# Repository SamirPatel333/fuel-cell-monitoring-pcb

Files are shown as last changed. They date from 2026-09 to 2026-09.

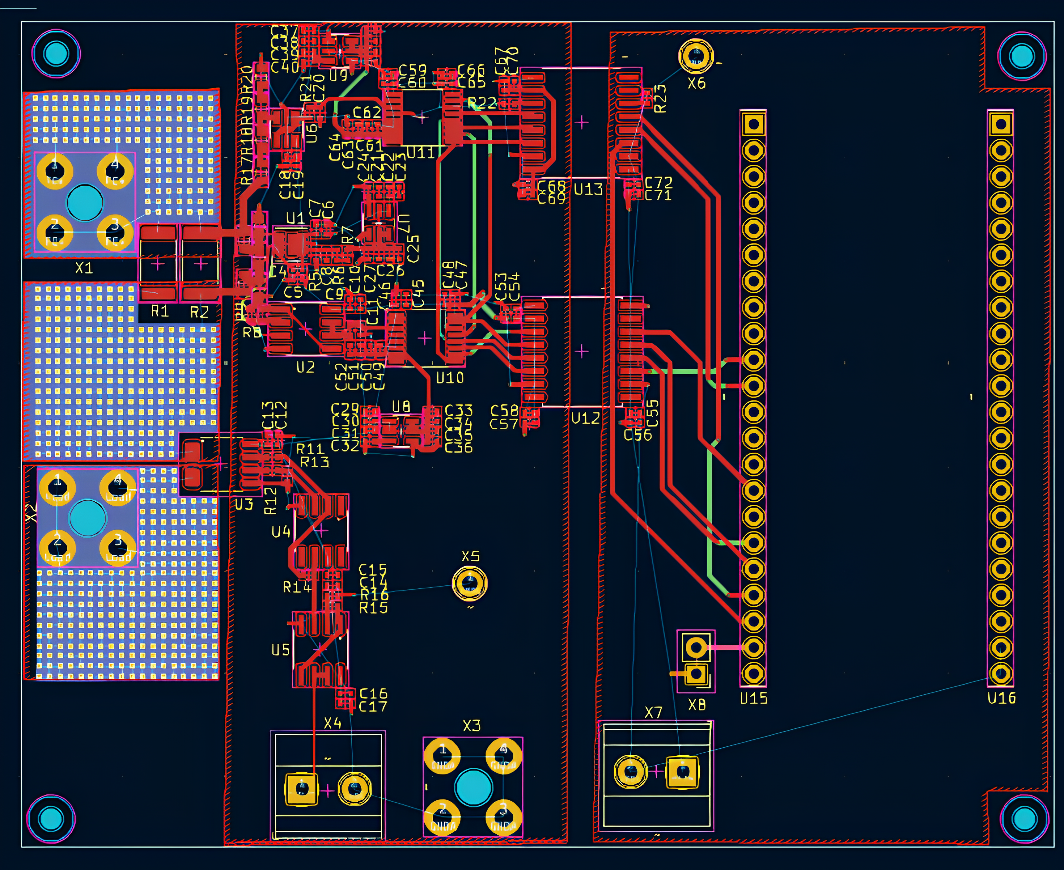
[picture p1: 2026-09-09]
Docs/Images/PCB_layout.png

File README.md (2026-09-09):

# Fuel Cell Monitoring System – 6-Layer PCB

## Overview

A custom **6-layer mixed-signal PCB** designed in **KiCad** for monitoring a **PEM fuel cell system**.

The board measures fuel-cell voltage and current, conditions the analog signals, performs ADC conversion, provides digital isolation, and interfaces with an **ESP32-S3**.

## Main Features

- Fuel-cell voltage measurement
- Fuel-cell current measurement up to 20 A
- Analog signal conditioning and filtering
- Precision voltage references
- High-resolution ADC measurement
- Digital isolation
- ESP32-S3 interface

## Main Components

| Component | Function |
|---|---|
| ESP32-S3 | Microcontroller |
| ADS8329 | ADC |
| MAX49925 | Current measurement |
| MAX6070 | Precision voltage reference |
| AD8031 / AD8032 | Analog signal conditioning |
| ADA4099 | Precision analog amplifier |

## PCB Design

The PCB is designed as a **6-layer mixed-signal board** using KiCad.

The multilayer design supports:

- Analog and digital signal separation
- Stable power and ground distribution
- Sensitive ADC signal routing
- High-current routing
- Improved signal integrity and noise performance

## Design Tools

- KiCad – Schematic capture and PCB layout
- ESP32-S3 – Microcontroller interface
- Multilayer PCB design for mixed-signal applications

## Project Structure

- `Kicad/` – KiCad schematics, PCB layout, symbols and footprints
- `Docs/` – Project report and documentation images
- `.gitignore` – Files excluded from Git tracking

## Project Status

PCB schematic and 6-layer PCB layout completed in KiCad.

## Future Improvements

- PCB manufacturing and assembly
- Hardware testing and calibration
- ESP32-S3 firmware development
- Measurement accuracy and noise evaluation

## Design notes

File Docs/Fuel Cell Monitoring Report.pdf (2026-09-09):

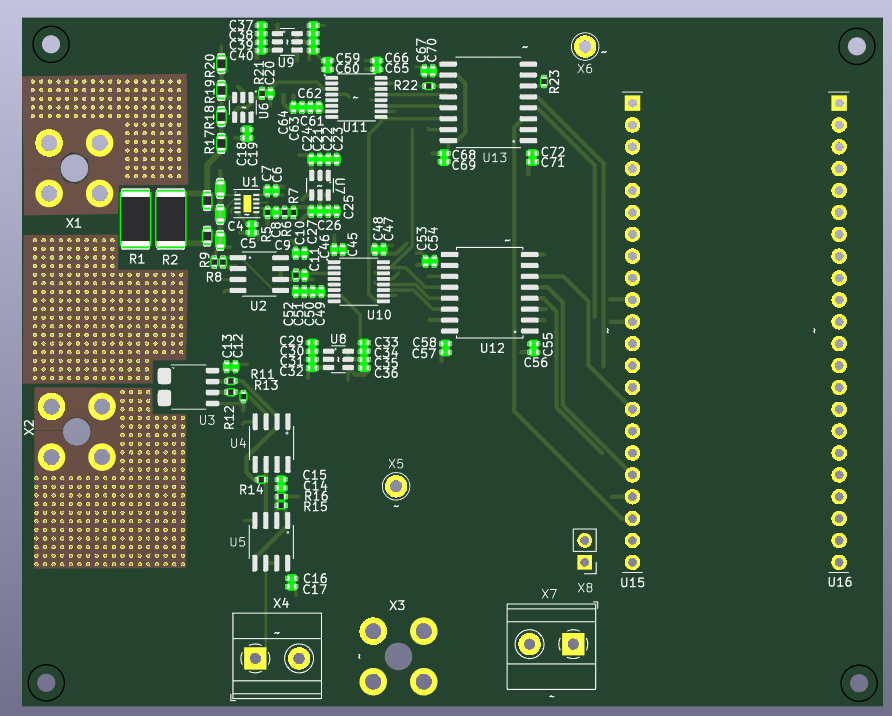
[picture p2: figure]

Fuel Cell Monitoring System | Six-Layer PCB Design | Page 1

# FUEL CELL MONITORING SYSTEM

### Six-Layer PCB Design & Hardware Engineering Report

Figure 1. 3D visualization of the completed six-layer PCB layout.

Project | Fuel Cell Monitoring System
PCB Technology | 6-layer printed circuit board
EDA Tool | KiCad
Controller | ESP32-S3
Measurement Functions | Fuel-cell voltage and current monitoring
Author | Samir Patel
Institution | Hochschule Wismar – Faculty of Engineering Sciences

## Engineering Report

This report documents the schematic architecture, measurement signal conditioning, ADC and isolation interfaces, reference-voltage generation, microcontroller interface, and six-layer PCB implementation developed for a fuel-cell monitoring application.

# Contents

### 1 Project Overview

### 2 System Architecture

### 3 Voltage Measurement Chain

### 4 Current Measurement Chain

### 5 Voltage References and Power Integrity

### 6 ADC, Digital Isolation and SPI Interface

### 7 Microcontroller Interface

### 8 Six-Layer PCB Design and Layout

### 9 Design-for-Manufacture and Verification

### 10 Engineering Assessment

### 11 Conclusion and Future Improvements

## List of Figures

- Figure 1. 3D visualization of the six-layer PCB.
- Figure 2. KiCad PCB layout and routing view.
- Figure 3. Main current/voltage measurement circuitry.
- Figure 4. Voltage measurement and conditioning stage.
- Figure 5. Precision reference-voltage circuits.
- Figure 6. ADC and digital-isolation interface – channel 1.
- Figure 7. ADC and digital-isolation interface – channel 2.
- Figure 8. ESP32-S3 microcontroller interface.

# 1. Project Overview

The project is a dedicated electronic monitoring board for a fuel-cell system. The hardware is designed to acquire electrical operating quantities, condition them for accurate analog-to-digital conversion, provide isolation where required, and transfer the resulting measurement data to an ESP32-S3 microcontroller through digital interfaces.

## Main engineering objectives

- Measure the fuel-cell output voltage using a conditioned analog measurement path.
- Measure fuel-cell current using a dedicated current-sensing stage.
- Scale, buffer and filter analog signals before ADC conversion.
- Provide stable analog reference voltages for repeatable measurement.
- Use digital isolation between measurement-side circuitry and the controller-side interface.
- Implement the complete design as a compact six-layer PCB in KiCad.
- Provide a layout suitable for further prototype fabrication, assembly and laboratory validation.

## Design philosophy

The design separates the analog measurement functions from the digital controller section. This is important because low-level measurement signals are sensitive to supply noise, return-current paths and digital switching activity. The use of dedicated filtering, buffering, reference circuitry and isolation supports a more controlled measurement environment.

# 2. System Architecture

The schematic is organized into functional blocks rather than treating the PCB as a single circuit. The principal signal flow is: fuel-cell input → sensing → analog conditioning → ADC → digital isolation → ESP32-S3 controller. Separate reference and supply-conditioning circuits support the measurement stages.

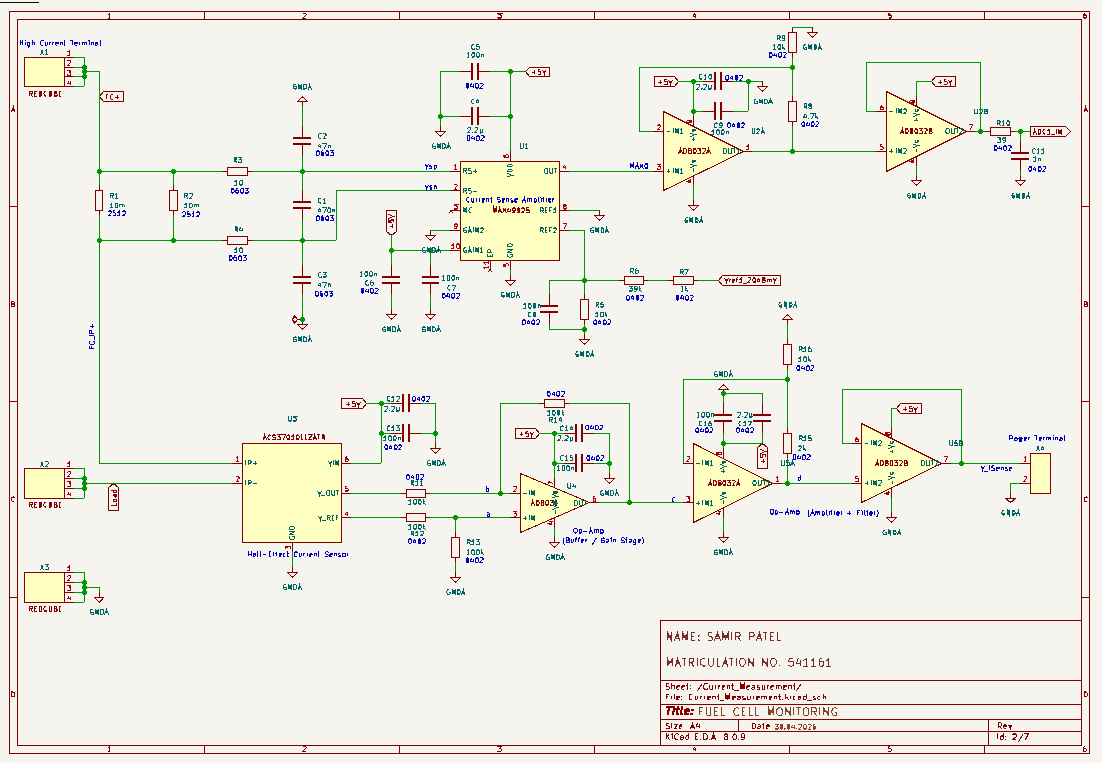
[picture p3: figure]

Figure 3. Main measurement circuitry showing voltage/current sensing, analog conditioning and output stages.

## Functional blocks visible in the design

- Fuel-cell electrical input and high-current connection interfaces.
- Voltage sensing network with resistor-divider scaling and filtering.
- Current measurement using a dedicated current-sensing device and amplifier chain.
- Operational-amplifier stages for buffering, gain and signal conditioning.
- Precision voltage-reference sections with local decoupling.
- High-resolution ADC interfaces for digitizing conditioned measurement signals.
- Digital isolators for separation of the measurement and controller domains.
- ESP32-S3 interface and SPI/control connections.

# 3. Voltage Measurement Chain

The voltage-monitoring section converts the fuel-cell voltage into a controlled low-voltage analog signal suitable for the ADC input range. The front end uses resistor scaling, followed by filtering and an amplifier/buffer stage. This approach prevents the high-voltage source from being connected directly to the ADC while maintaining a defined measurement relationship.

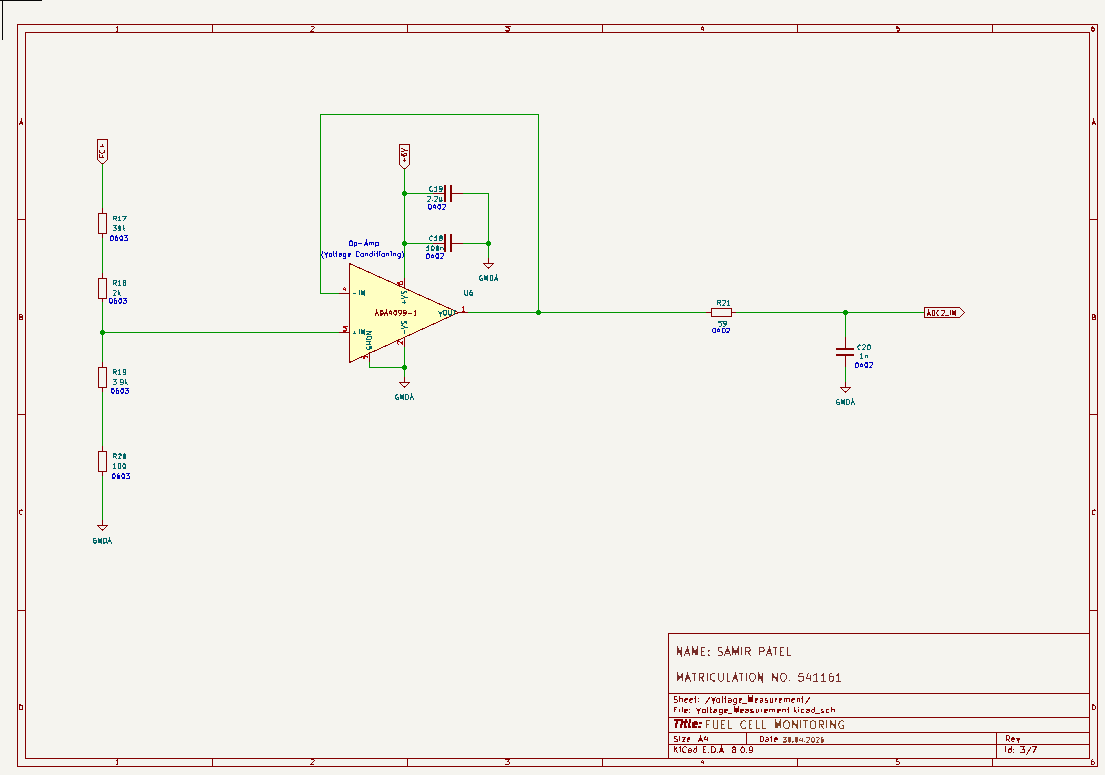
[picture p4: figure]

Figure 4. Voltage measurement and conditioning stage in KiCad.

## Key design considerations

- The resistor divider establishes the input scaling ratio.
- RC filtering reduces high-frequency noise before conversion.
- The op-amp stage provides buffering and/or additional signal conditioning.
- The final signal is routed to the ADC through a controlled analog path.
- Local supply decoupling is used around active devices.

## Measurement relationship

For a basic divider, the scaled voltage is determined by the resistor ratio. During laboratory calibration, the actual board should be characterized using a known reference voltage and the measured ADC code should be mapped to the physical fuel-cell voltage. Component tolerances, amplifier offset and ADC reference accuracy should be included in the final error budget.

# 4. Current Measurement Chain

The current-monitoring path uses a dedicated current-sensing element followed by analog signal conditioning. The schematic includes amplifier stages that prepare the sensor output for ADC conversion. The design therefore allows the low-level current-sense signal to be amplified and filtered before digitization.

## Signal-conditioning strategy

- Current sensor generates a signal proportional to the measured current.
- An amplifier stage increases the useful signal level.
- RC networks provide bandwidth limitation and noise suppression.
- The conditioned signal is transferred to the ADC input.
- The final current value can be calculated in firmware from ADC code and the calibrated sensor transfer function.

The current channel should be calibrated at several known operating points rather than using only one point. A two-point or multi-point calibration can compensate for gain and offset errors and provide better accuracy over the operating range.

# 5. Voltage References and Power Integrity

Stable reference voltages are essential for accurate ADC measurements. The design contains dedicated reference-voltage circuits with multiple bypass capacitors placed around the reference devices. The repeated reference blocks indicate an intentional effort to provide clean reference rails for the measurement channels.

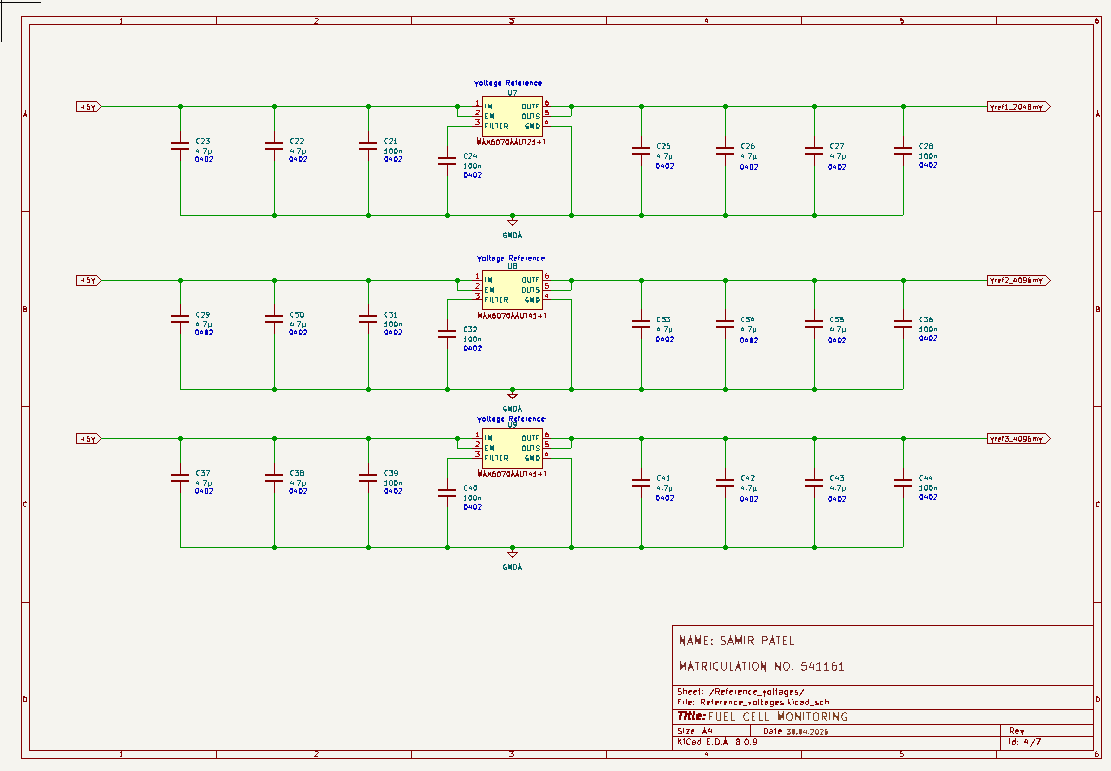
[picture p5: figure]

Figure 5. Dedicated voltage-reference circuits with local bypass capacitors.

## Power-integrity practices

- Place high-frequency bypass capacitors close to IC supply/reference pins.
- Keep sensitive reference routing away from noisy digital traces where practical.
- Use a controlled return path for analog circuitry.
- Avoid unnecessary shared impedance between high-current and low-level measurement returns.
- Verify reference output voltage and noise experimentally during board bring-up.

# 6. ADC, Digital Isolation and SPI Interface

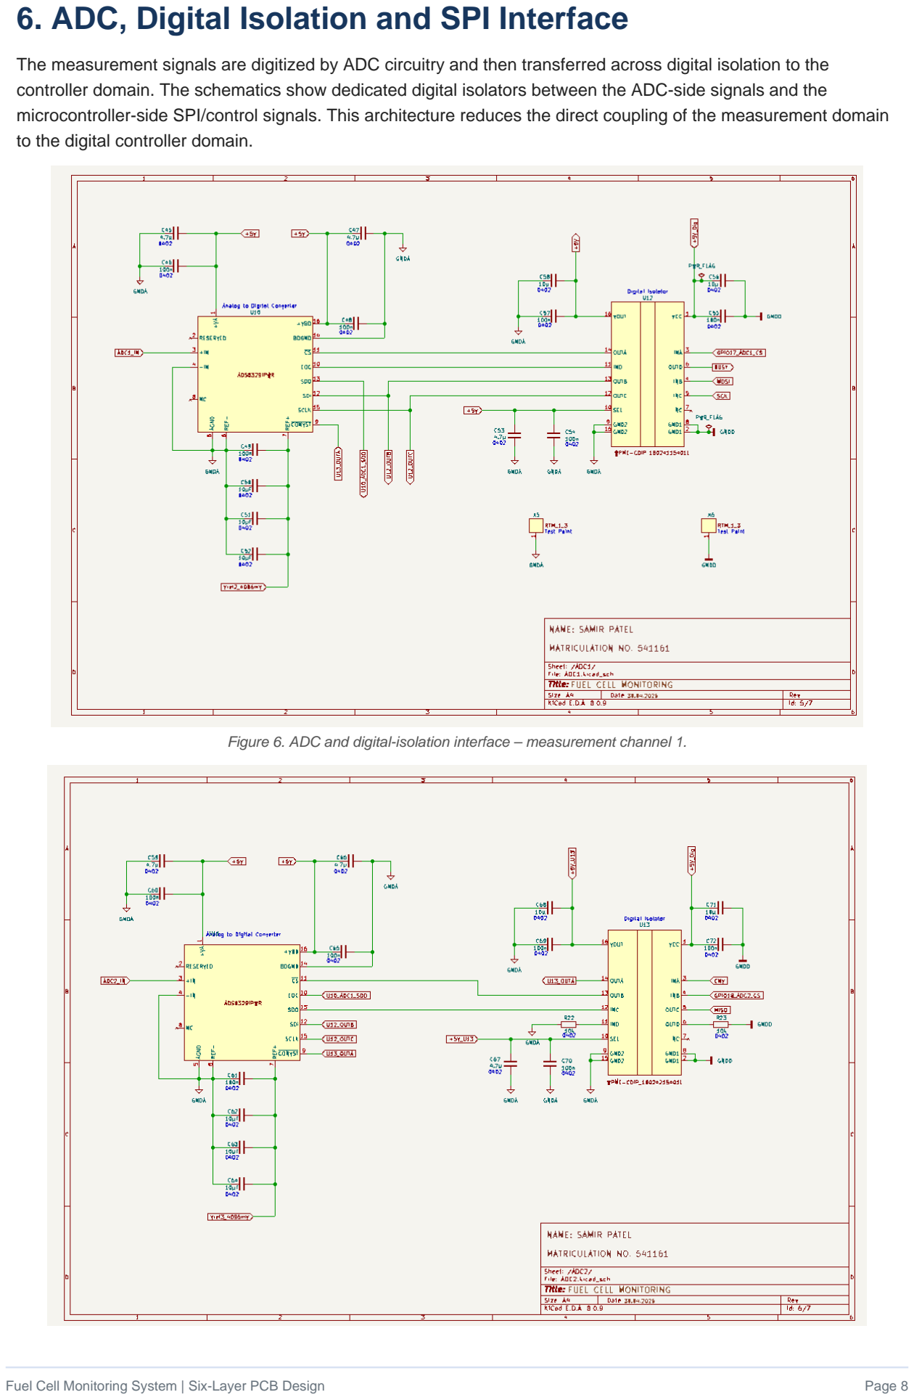
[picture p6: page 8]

The measurement signals are digitized by ADC circuitry and then transferred across digital isolation to the controller domain. The schematics show dedicated digital isolators between the ADC-side signals and the microcontroller-side SPI/control signals. This architecture reduces the direct coupling of the measurement domain to the digital controller domain.

Figure 6. ADC and digital-isolation interface – measurement channel 1.

Figure 7. ADC and digital-isolation interface – measurement channel 2.

## Interface signals

- SPI clock and data signals connect the ADC and controller interface.
- Chip-select and control lines are routed through the digital interface.
- Isolated power domains are supported by local decoupling.
- The PCB layout keeps the digital interface physically separated from the most sensitive analog nodes where practical.

# 7. Microcontroller Interface

The controller section is centered around an ESP32-S3 module. The schematic provides the required power, ground and digital signal connections for communication with the measurement subsystem. The large board-side header area provides flexibility for programming, debugging and system integration.

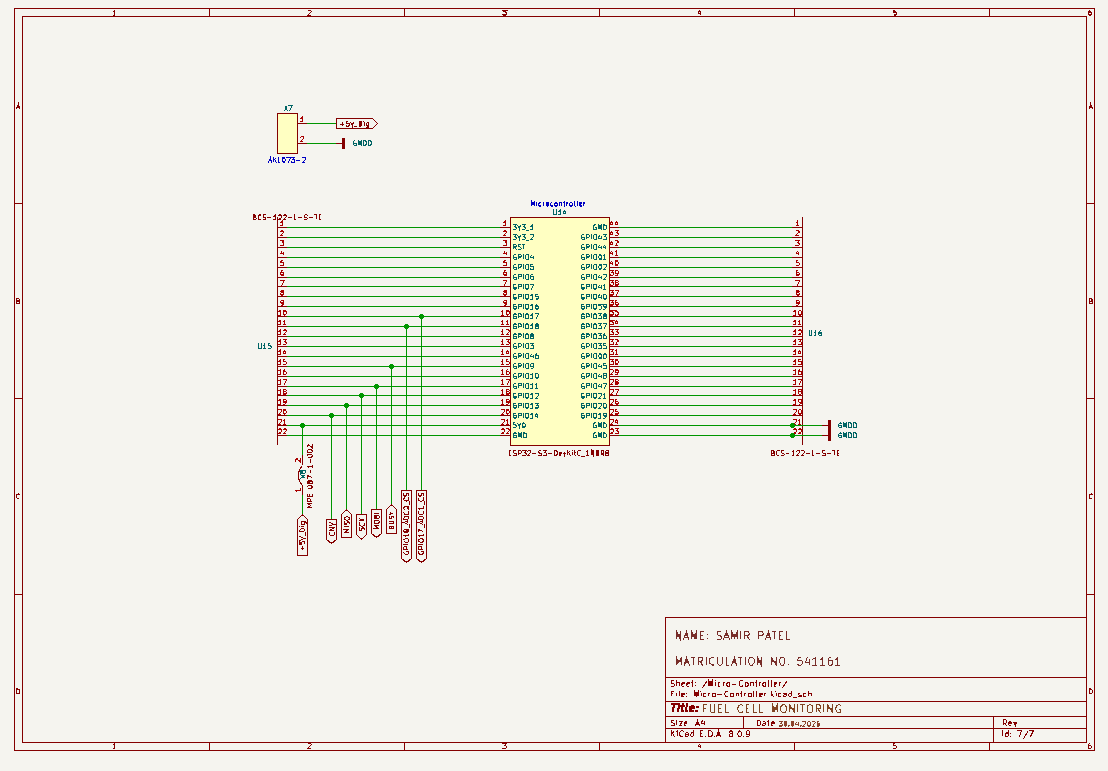
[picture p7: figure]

Figure 8. ESP32-S3 microcontroller and external interface connections.

## Recommended firmware responsibilities

- Initialize the ADC/SPI interface and digital-isolation control signals.
- Read raw ADC conversion results.
- Apply gain, offset and calibration coefficients.
- Convert ADC results into engineering units such as volts and amperes.
- Provide diagnostic checks for out-of-range or invalid measurements.
- Transmit measurements through the selected communication interface.

# 8. Six-Layer PCB Design and Layout

The board was implemented as a six-layer PCB. The higher layer count provides additional routing and plane resources compared with a basic two-layer design and is particularly useful for a mixed-signal board containing precision analog circuitry, ADCs, digital isolation and a microcontroller interface.

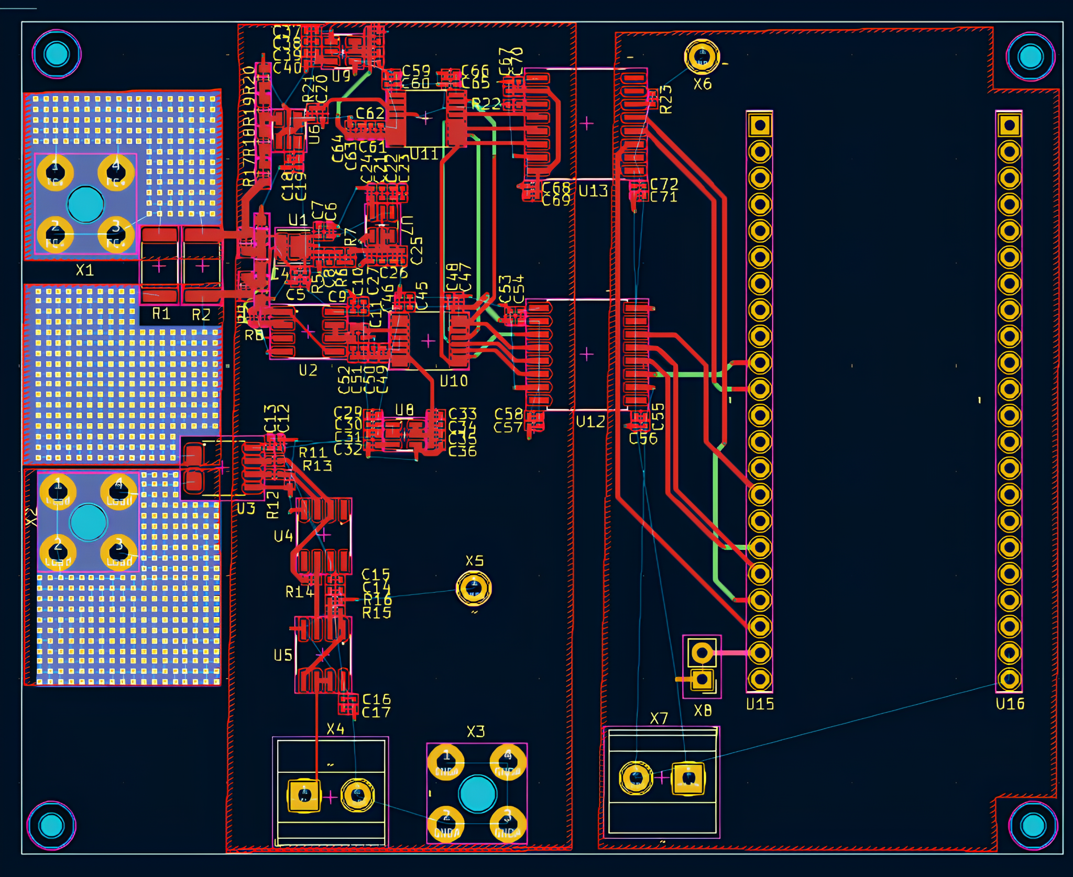
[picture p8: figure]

Figure 2. KiCad PCB layout view showing component placement and routed traces.

## Layout strategy

- High-current/input connector regions are kept toward the board edge.
- Analog sensing and conditioning circuitry is concentrated in the left/central area.
- ADC and isolation circuitry forms an interface between analog and digital sections.
- The controller/header area is separated from the most sensitive analog circuitry.
- Large connector/header footprints provide system-level access and expansion.
- Mounting holes and mechanical keep-out areas are incorporated into the board outline.

## Six-layer mixed-signal considerations

- Use dedicated or carefully controlled ground/reference planes.
- Keep fast digital routes away from sensitive analog inputs.
- Minimize loop area for ADC reference, amplifier feedback and decoupling paths.
- Route high-current paths with appropriate copper width and thermal considerations.
- Use short connections between IC supply pins and local bypass capacitors.
- Validate all clearances, drill sizes, annular rings and copper-to-edge rules against the selected PCB manufacturer.

# 9. Design-for-Manufacture and Verification

Before fabrication, the KiCad project should be treated as a manufacturing data package rather than only a layout. The following checks are recommended for the final revision.

Area | Verification item | Status
Schematic | ERC completed and all intentional warnings reviewed | Check before release
PCB | DRC completed with no unexplained violations | Check before release
Footprints | Pad geometry, pin-1 orientation and mechanical dimensions verified | Check before release
Layers | Six copper layers and stack-up confirmed with manufacturer | Confirmed by project
Power | Supply rails and polarity checked | Check before release
References | Reference outputs measured under load | Prototype test
ADC | Input range and reference voltage verified | Prototype test
Isolation | Isolation barrier and creepage/clearance verified | Prototype test
Calibration | Voltage/current calibration coefficients established | Prototype test
Fabrication | Gerbers, drill files and assembly documentation generated | Release step

## Recommended release package

- KiCad project files: schematic, PCB layout, symbols and footprints.
- Fabrication outputs: Gerber and drill files for the six-layer stack-up.
- Bill of materials (BOM) with manufacturer part numbers.
- Pick-and-place data if automated assembly is used.
- PDF schematic and PCB drawings for documentation.
- Calibration and test procedure for prototype validation.

# 10. Engineering Assessment

The design demonstrates a complete hardware-development workflow from electrical sensing and analog conditioning through data conversion, digital isolation and microcontroller interfacing. The use of a six-layer PCB is appropriate for the density and mixed-signal nature of the design and gives the layout additional resources for signal integrity and power/ground distribution.

## Strengths of the current design

- Clear separation of major analog, conversion, isolation and controller functions.
- Dedicated analog conditioning before ADC conversion.
- Dedicated voltage-reference circuitry with multiple local capacitors.
- Digital isolation between measurement and controller interfaces.
- Compact six-layer PCB implementation with integrated connectors and mounting features.
- KiCad-based design is suitable for reproducible revision and manufacturing documentation.

## Areas to improve in the next revision

- Perform a complete quantitative error budget for voltage and current channels.
- Document the exact six-layer stack-up, copper thickness and impedance requirements.
- Add clearly documented test points for each major analog signal and supply rail.
- Review analog/digital return-current paths with particular attention to ADC reference and isolation boundaries.
- Complete prototype measurements for noise, offset, gain error and temperature drift.
- Add revision-controlled manufacturing and assembly documentation.

# 11. Conclusion and Future Improvements

A complete six-layer PCB-based fuel-cell monitoring platform has been developed in KiCad. The board integrates fuel-cell voltage and current measurement, analog signal conditioning, precision reference circuitry, ADC conversion, digital isolation and ESP32-S3 interfacing on a single hardware platform.

The next stage should focus on prototype fabrication and laboratory characterization. In particular, the voltage and current channels should be calibrated against traceable instruments, while ADC noise, amplifier offset, reference stability and thermal behavior should be measured. These results can then be used to refine component values, PCB routing and firmware calibration.

## Future development opportunities

- Add automated self-test and sensor fault detection.
- Implement digital filtering and configurable sampling rates in firmware.
- Add non-volatile storage for calibration coefficients.
- Provide a dedicated communication interface for PC or cloud-based monitoring.
- Improve test-point accessibility for production and laboratory debugging.
- Document and validate the complete PCB stack-up and EMC/EMI performance.
Document status | Professional project documentation
PCB revision | Six-layer design
Design tool | KiCad
Primary controller | ESP32-S3
Next milestone | Prototype fabrication and electrical validation

### End of Report

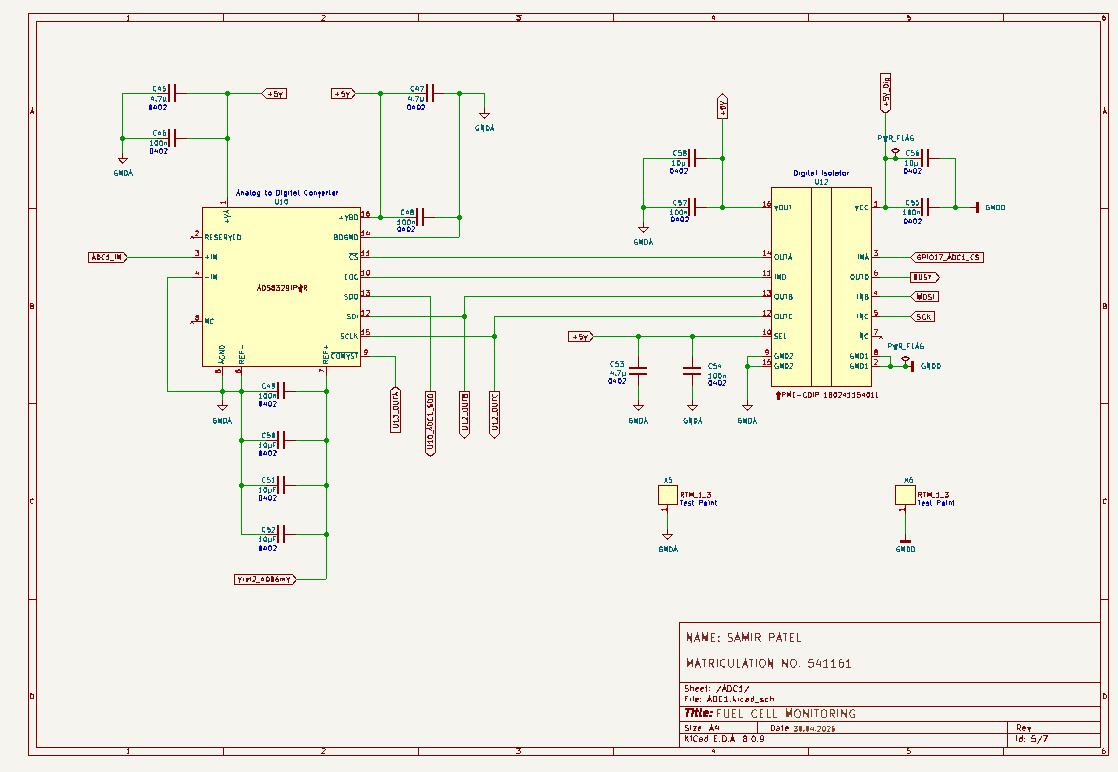
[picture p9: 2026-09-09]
Docs/Images/Schematic/ADC_1.png

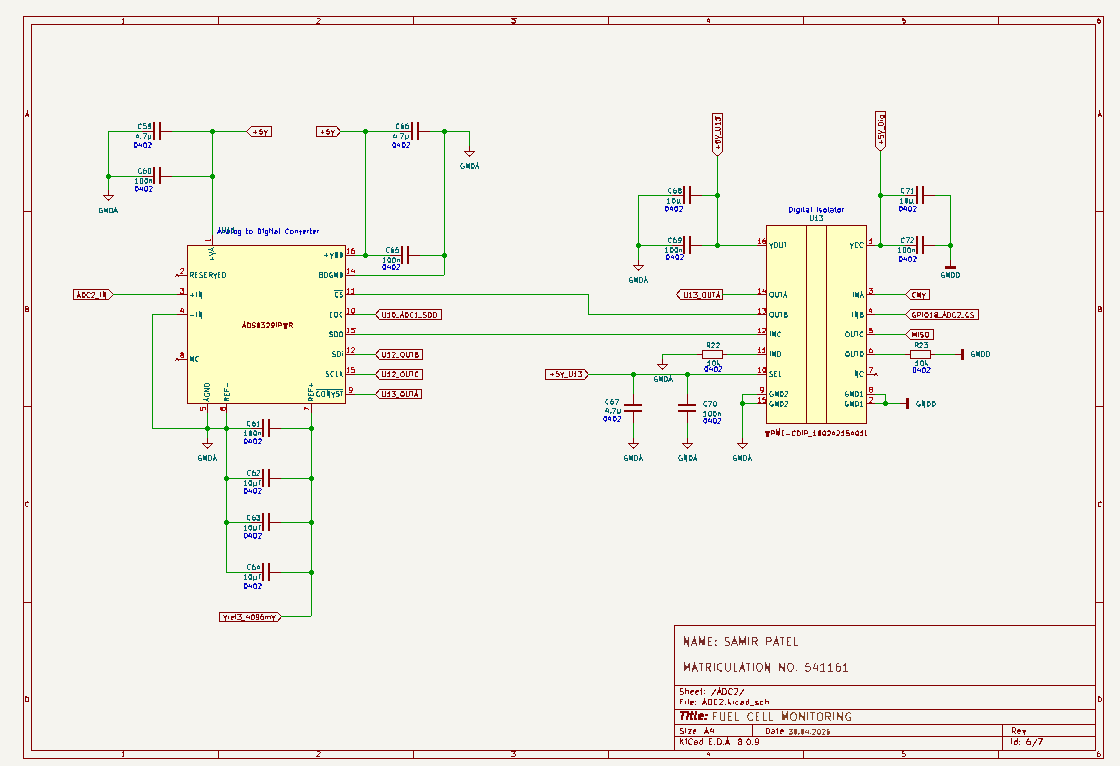
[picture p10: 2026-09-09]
Docs/Images/Schematic/ADC_2.png

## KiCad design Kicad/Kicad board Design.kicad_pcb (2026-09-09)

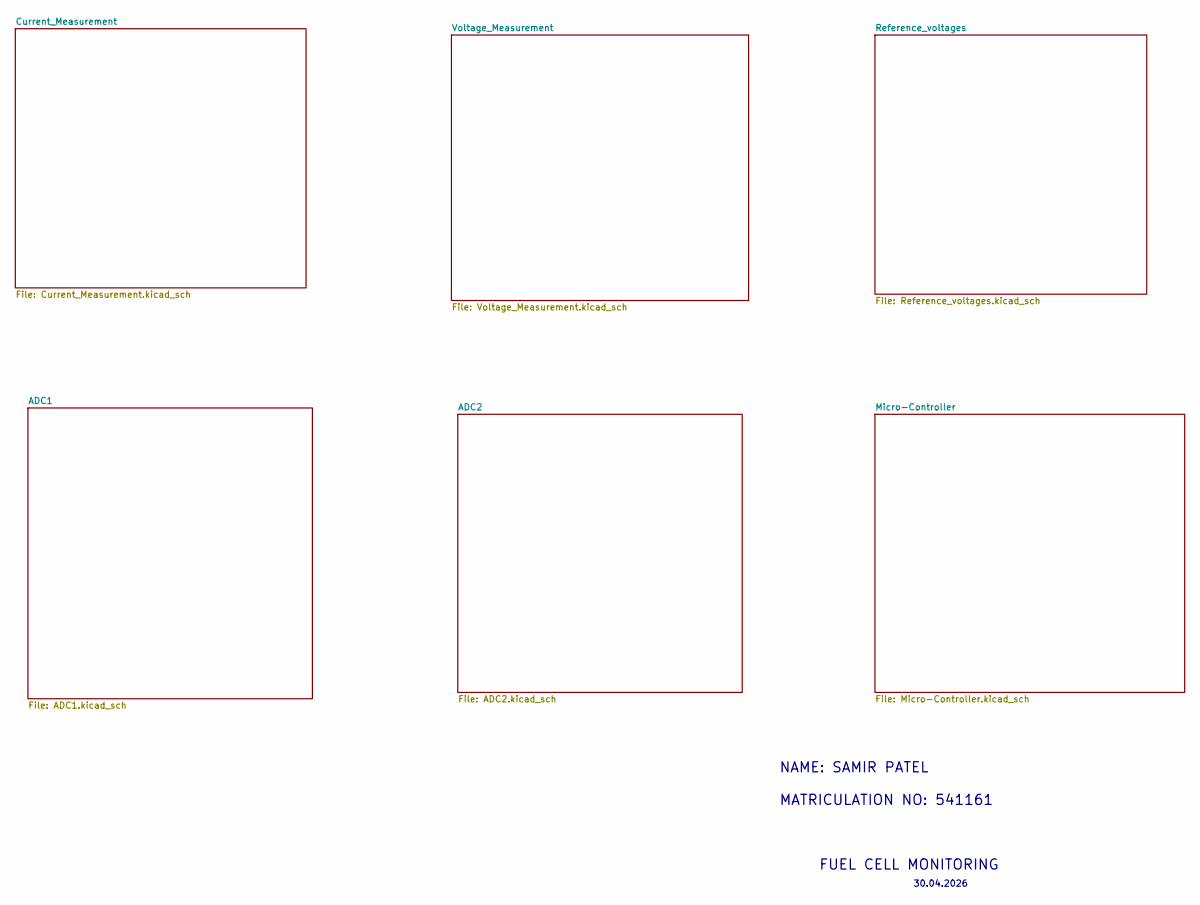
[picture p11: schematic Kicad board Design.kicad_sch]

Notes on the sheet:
FUEL CELL MONITORING
30.04.2026
NAME: SAMIR PATEL MATRICULATION NO: 541161

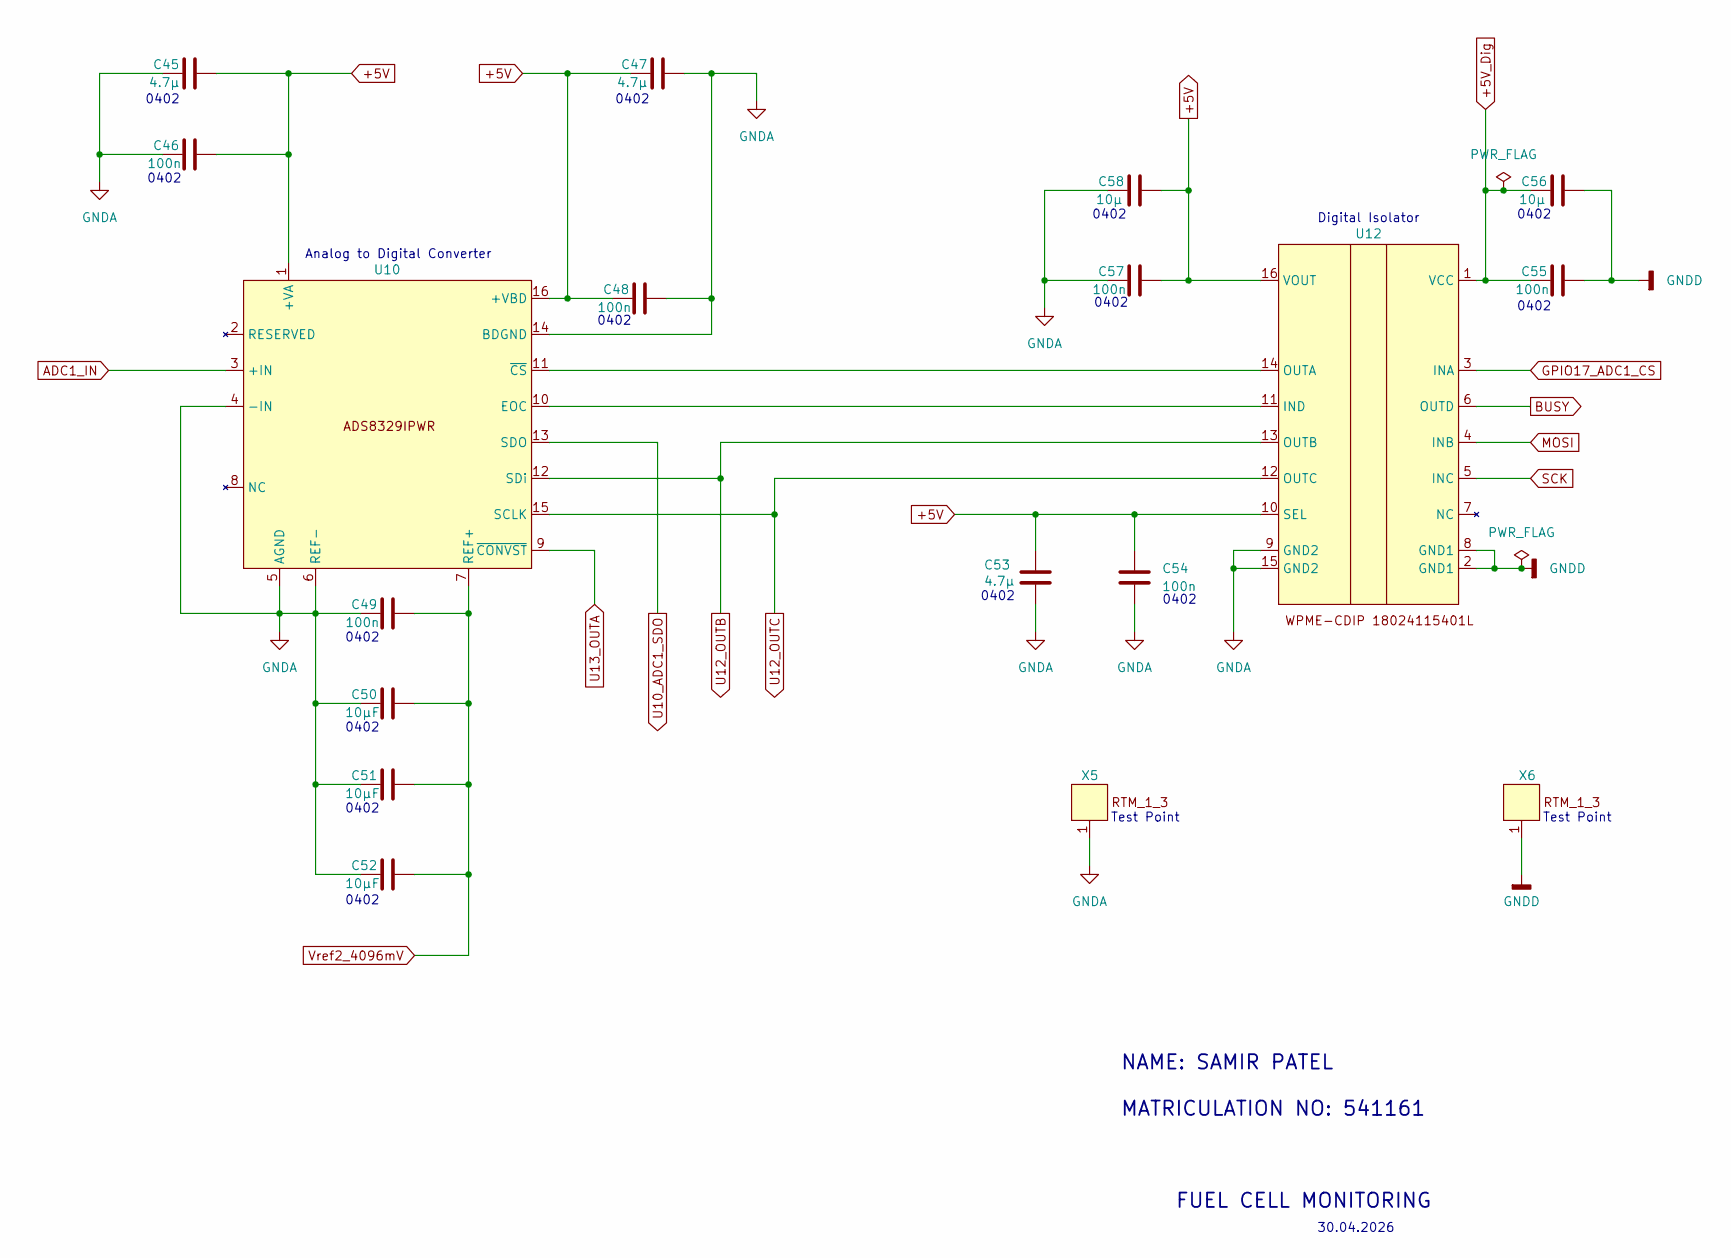
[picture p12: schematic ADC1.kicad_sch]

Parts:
C45, C47, C53: 4.7µ; C_0402_1005Metric
C46, C48, C49, C54, C55, C57: 100n; C_0402_1005Metric
C50, C51, C52: 10µF; C_0402_1005Metric
C56, C58: 10µ; C_0402_1005Metric
U10: ADS8329IPWR
U12: WPME-CDIP 18024115401L
X5, X6: RTM_1_3

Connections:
+5V: C45.2, C46.2, C47.1, C48.1, C53.1, C54.1, C57.2, C58.2, U10.1 (+VA), U10.16 (+VBD), U12.10 (SEL), U12.16 (VOUT); also elsewhere on the board
+5V_Dig: C55.1, C56.1, U12.1 (VCC); also elsewhere on the board
ADC1_IN: U10.3 (+IN); also elsewhere on the board
BUSY: U12.6 (OUTD); also elsewhere on the board
GNDA: C45.1, C46.1, C47.2, C48.2, C49.1, C50.1, C51.1, C52.1, C53.2, C54.2, C57.1, C58.1, U10.4 (-IN), U10.5 (AGND), U10.6 (REF-), U10.14 (BDGND), U12.9 (GND2), U12.15 (GND2), X5.1; also elsewhere on the board
GNDD: C55.2, C56.2, U12.2 (GND1), U12.8 (GND1), X6.1; also elsewhere on the board
GPIO17_ADC1_CS: U12.3 (INA); also elsewhere on the board
MOSI: U12.4 (INB); also elsewhere on the board
unnamed: U10.10 (EOC), U12.11 (IND)
unnamed: U10.11 (~CS), U12.14 (OUTA)
SCK: U12.5 (INC); also elsewhere on the board
U10_ADC1_SDO: U10.13 (SDO); also elsewhere on the board
U12_OUTB: U10.12 (SDi), U12.13 (OUTB); also elsewhere on the board
U12_OUTC: U10.15 (SCLK), U12.12 (OUTC); also elsewhere on the board
U13_OUTA: U10.9 (~CONVST); also elsewhere on the board
Vref2_4096mV: C49.2, C50.2, C51.2, C52.2, U10.7 (REF+); also elsewhere on the board

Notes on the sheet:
0402
Test Point
Analog to Digital Converter
NAME: SAMIR PATEL MATRICULATION NO: 541161
30.04.2026
Digital Isolator
FUEL CELL MONITORING

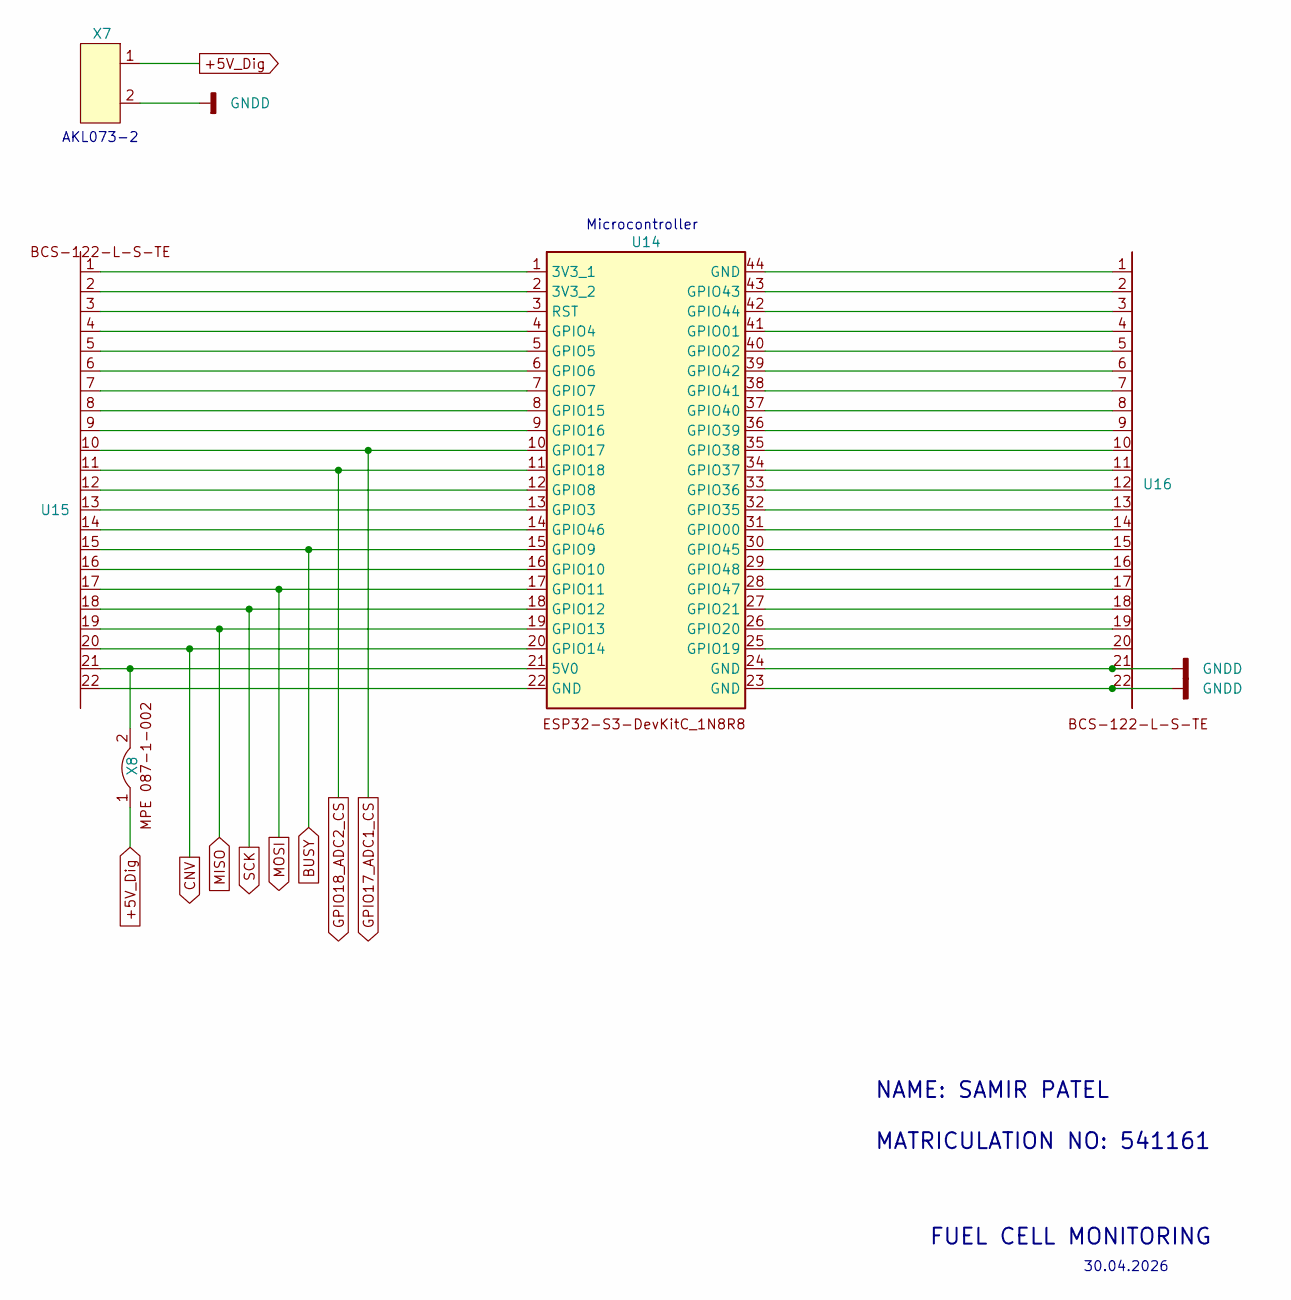
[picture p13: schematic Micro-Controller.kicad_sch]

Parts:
U14: ESP32-S3-DevkitC-1N8R8
U15, U16: BCS-122-L-S-TE
X7: AKL073-2
X8: MPE_087

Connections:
+5V_Dig: X7.1, X8.1; also elsewhere on the board
BUSY: U14.15 (GPIO9), U15.15; also elsewhere on the board
CNV: U14.20 (GPIO14), U15.20; also elsewhere on the board
GNDD: U14.23 (GND), U14.24 (GND), U16.21, U16.22, X7.2; also elsewhere on the board
GPIO17_ADC1_CS: U14.10 (GPIO17), U15.10; also elsewhere on the board
GPIO18_ADC2_CS: U14.11 (GPIO18), U15.11; also elsewhere on the board
MISO: U14.19 (GPIO13), U15.19; also elsewhere on the board
MOSI: U14.17 (GPIO11), U15.17; also elsewhere on the board
unnamed: U14.1 (3V3_1), U15.1
unnamed: U14.2 (3V3_2), U15.2
unnamed: U14.3 (RST), U15.3
unnamed: U14.4 (GPIO4), U15.4
unnamed: U14.5 (GPIO5), U15.5
unnamed: U14.6 (GPIO6), U15.6
unnamed: U14.7 (GPIO7), U15.7
unnamed: U14.8 (GPIO15), U15.8
unnamed: U14.9 (GPIO16), U15.9
unnamed: U14.12 (GPIO8), U15.12
unnamed: U14.13 (GPIO3), U15.13
unnamed: U14.14 (GPIO46), U15.14
unnamed: U14.16 (GPIO10), U15.16
unnamed: U14.21 (5V0), U15.21, X8.2
unnamed: U14.22 (GND), U15.22
unnamed: U14.44 (GND), U16.1
unnamed: U14.43 (GPIO43), U16.2
unnamed: U14.42 (GPIO44), U16.3
unnamed: U14.41 (GPIO01), U16.4
unnamed: U14.40 (GPIO02), U16.5
unnamed: U14.39 (GPIO42), U16.6
unnamed: U14.38 (GPIO41), U16.7
unnamed: U14.37 (GPIO40), U16.8
unnamed: U14.36 (GPIO39), U16.9
unnamed: U14.35 (GPIO38), U16.10
unnamed: U14.34 (GPIO37), U16.11
unnamed: U14.33 (GPIO36), U16.12
unnamed: U14.32 (GPIO35), U16.13
unnamed: U14.31 (GPIO00), U16.14
unnamed: U14.30 (GPIO45), U16.15
unnamed: U14.29 (GPIO48), U16.16
unnamed: U14.28 (GPIO47), U16.17
unnamed: U14.27 (GPIO21), U16.18
unnamed: U14.26 (GPIO20), U16.19
unnamed: U14.25 (GPIO19), U16.20
SCK: U14.18 (GPIO12), U15.18; also elsewhere on the board

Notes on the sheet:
30.04.2026
Microcontroller
NAME: SAMIR PATEL MATRICULATION NO: 541161
FUEL CELL MONITORING
AKL073-2

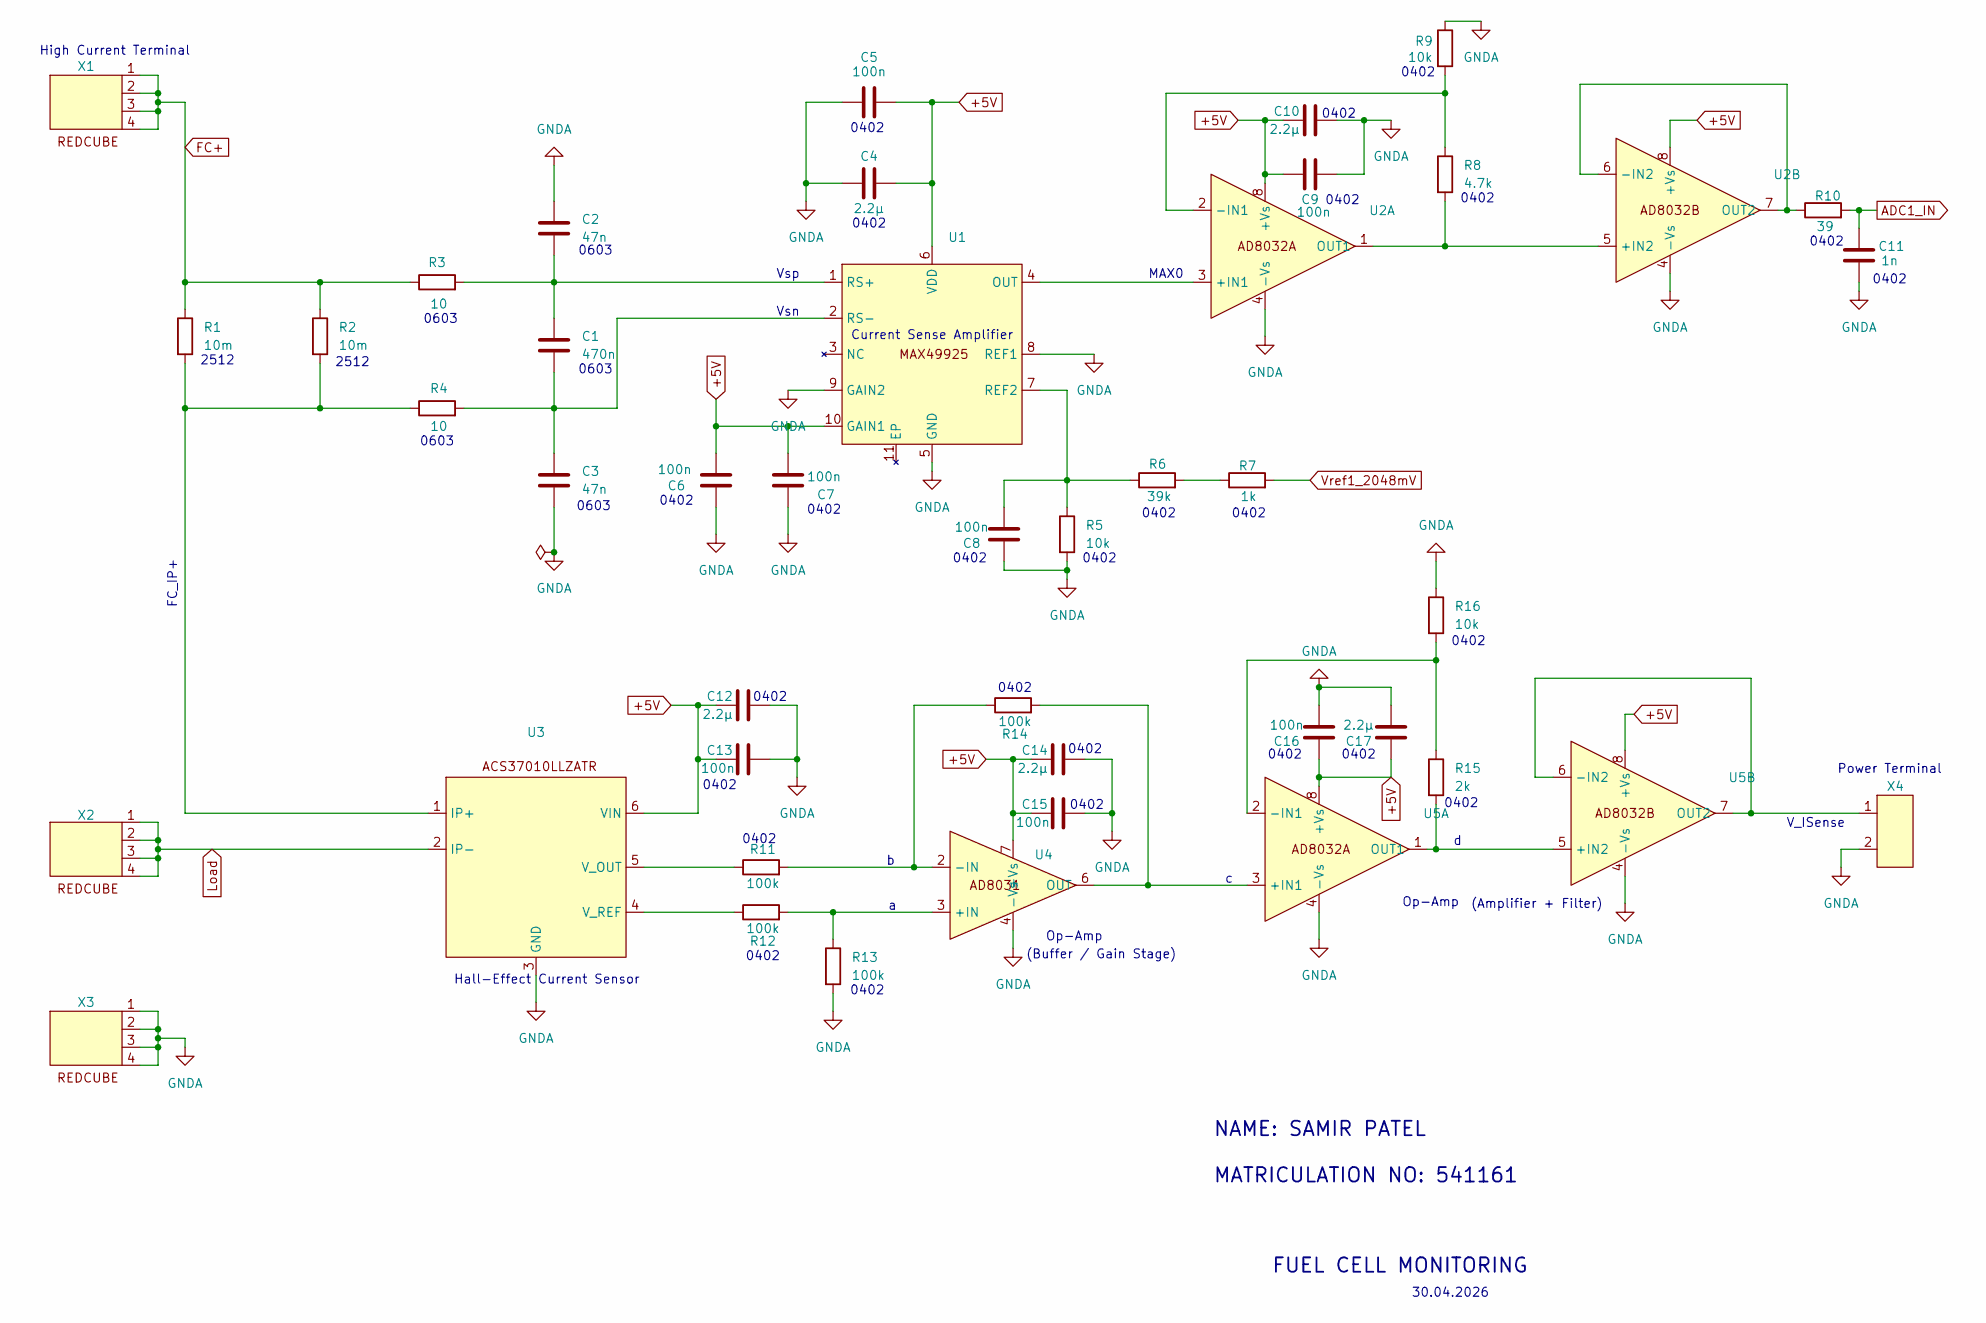
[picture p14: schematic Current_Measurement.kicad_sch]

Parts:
C1: 470n; C_0603_1608Metric
C2, C3: 47n; C_0603_1608Metric
C4, C10, C12, C14, C17: 2.2µ; C_0402_1005Metric
C5, C6, C7, C8, C9, C13, C15, C16: 100n; C_0402_1005Metric
C11: 1n; C_0402_1005Metric
R1, R2: 10m; R_2512_6332Metric
R3, R4: 10; R_0603_1608Metric
R5, R9, R16: 10k; R_0402_1005Metric
R6: 39k; R_0402_1005Metric
R7: 1k; R_0402_1005Metric
R8: 4.7k; R_0402_1005Metric
R10: 39; R_0402_1005Metric
R11, R12, R13, R14: 100k; R_0402_1005Metric
R15: 2k; R_0402_1005Metric
U1: MAX49925XATB+T
U2, U5: AD8032ARZ
U3: ACS37010LLZATR-030U5
U4: AD8031ARZ
X1, X2, X3: WP-THRBU_REDCUBE_74650073
X4: AKL073-2

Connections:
+5V: C4.2, C5.2, C6.1, C7.1, C9.1, C10.1, C12.1, C13.1, C14.1, C15.1, C16.2, C17.2, U1.6 (VDD), U1.10 (GAIN1), U2.8 (+Vs), U3.6 (VIN), U4.7 (+Vs), U5.8 (+Vs); also elsewhere on the board
ADC1_IN: C11.1, R10.2; also elsewhere on the board
FC+: R1.1, R2.1, R3.1, X1.1, X1.2, X1.3, X1.4; also elsewhere on the board
GNDA: C2.1, C3.2, C4.1, C5.1, C6.2, C7.2, C8.2, C9.2, C10.2, C11.2, C12.2, C13.2, C14.2, C15.2, C16.1, C17.1, R5.2, R9.1, R13.2, R16.1, U1.5 (GND), U1.8 (REF1), U1.9 (GAIN2), U2.4 (-Vs), U3.3 (GND), U4.4 (-Vs), U5.4 (-Vs), X3.1, X3.2, X3.3, X3.4, X4.2; also elsewhere on the board
Load: U3.2 (IP-), X2.1, X2.2, X2.3, X2.4
unnamed: R6.2, R7.1
unnamed: U1.4 (OUT), U2.3 (+IN1)
unnamed: C8.1, R5.1, R6.1, U1.7 (REF2)
unnamed: C1.1, C2.2, R3.2, U1.1 (RS+)
unnamed: C1.2, C3.1, R4.2, U1.2 (RS-)
unnamed: R8.1, R9.2, U2.2 (-IN1)
unnamed: R8.2, U2.1 (OUT1), U2.5 (+IN2)
unnamed: R10.1, U2.6 (-IN2), U2.7 (OUT2)
unnamed: R1.2, R2.2, R4.1, U3.1 (IP+)
unnamed: R11.1, U3.5 (V_OUT)
unnamed: R12.1, U3.4 (V_REF)
unnamed: R12.2, R13.1, U4.3 (+IN)
unnamed: R11.2, R14.1, U4.2 (-IN)
unnamed: R14.2, U4.6 (OUT), U5.3 (+IN1)
unnamed: R15.1, R16.2, U5.2 (-IN1)
unnamed: R15.2, U5.1 (OUT1), U5.5 (+IN2)
unnamed: U5.6 (-IN2), U5.7 (OUT2), X4.1
Vref1_2048mV: R7.2; also elsewhere on the board

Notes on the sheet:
Hall-Effect Current Sensor
0402
2512
0603
V_ISense
FUEL CELL MONITORING
Vsp
Current Sense Amplifier
NAME: SAMIR PATEL MATRICULATION NO: 541161
High Current Terminal
Vsn
30.04.2026
(Buffer / Gain Stage)
FC_IP+
Op-Amp
MAX0
(Amplifier + Filter)
Power Terminal

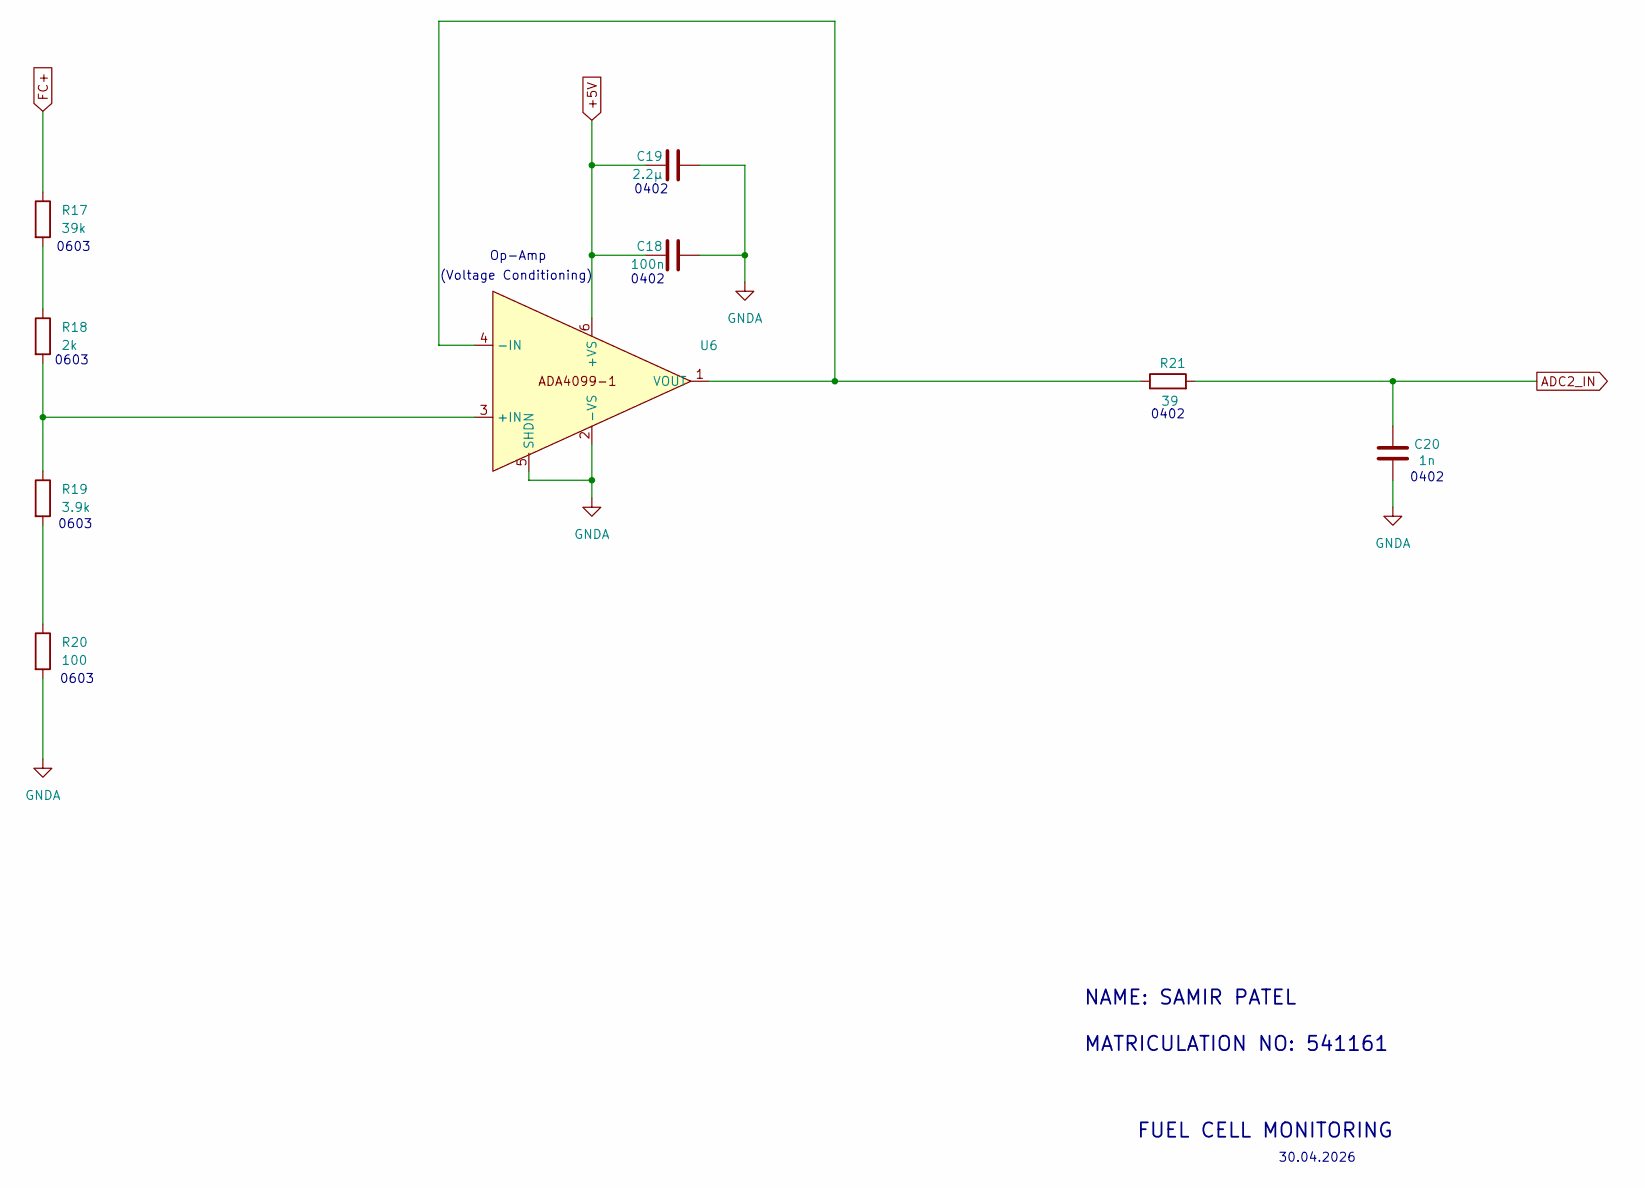
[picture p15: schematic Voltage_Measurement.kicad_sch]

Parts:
C18: 100n; C_0402_1005Metric
C19: 2.2µ; C_0402_1005Metric
C20: 1n; C_0402_1005Metric
R17: 39k; R_0603_1608Metric
R18: 2k; R_0603_1608Metric
R19: 3.9k; R_0603_1608Metric
R20: 100; R_0603_1608Metric
R21: 39; R_0402_1005Metric
U6: ADA4099-1BUJZ-RL7

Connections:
+5V: C18.1, C19.1, U6.6 (+VS); also elsewhere on the board
ADC2_IN: C20.1, R21.2; also elsewhere on the board
FC+: R17.1; also elsewhere on the board
GNDA: C18.2, C19.2, C20.2, R20.2, U6.2 (-VS), U6.5 (SHDN); also elsewhere on the board
unnamed: R17.2, R18.1
unnamed: R19.2, R20.1
unnamed: R18.2, R19.1, U6.3 (+IN)
unnamed: R21.1, U6.1 (VOUT), U6.4 (-IN)

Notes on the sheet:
0402
0603
(Voltage Conditioning)
FUEL CELL MONITORING
Op-Amp
NAME: SAMIR PATEL MATRICULATION NO: 541161
30.04.2026

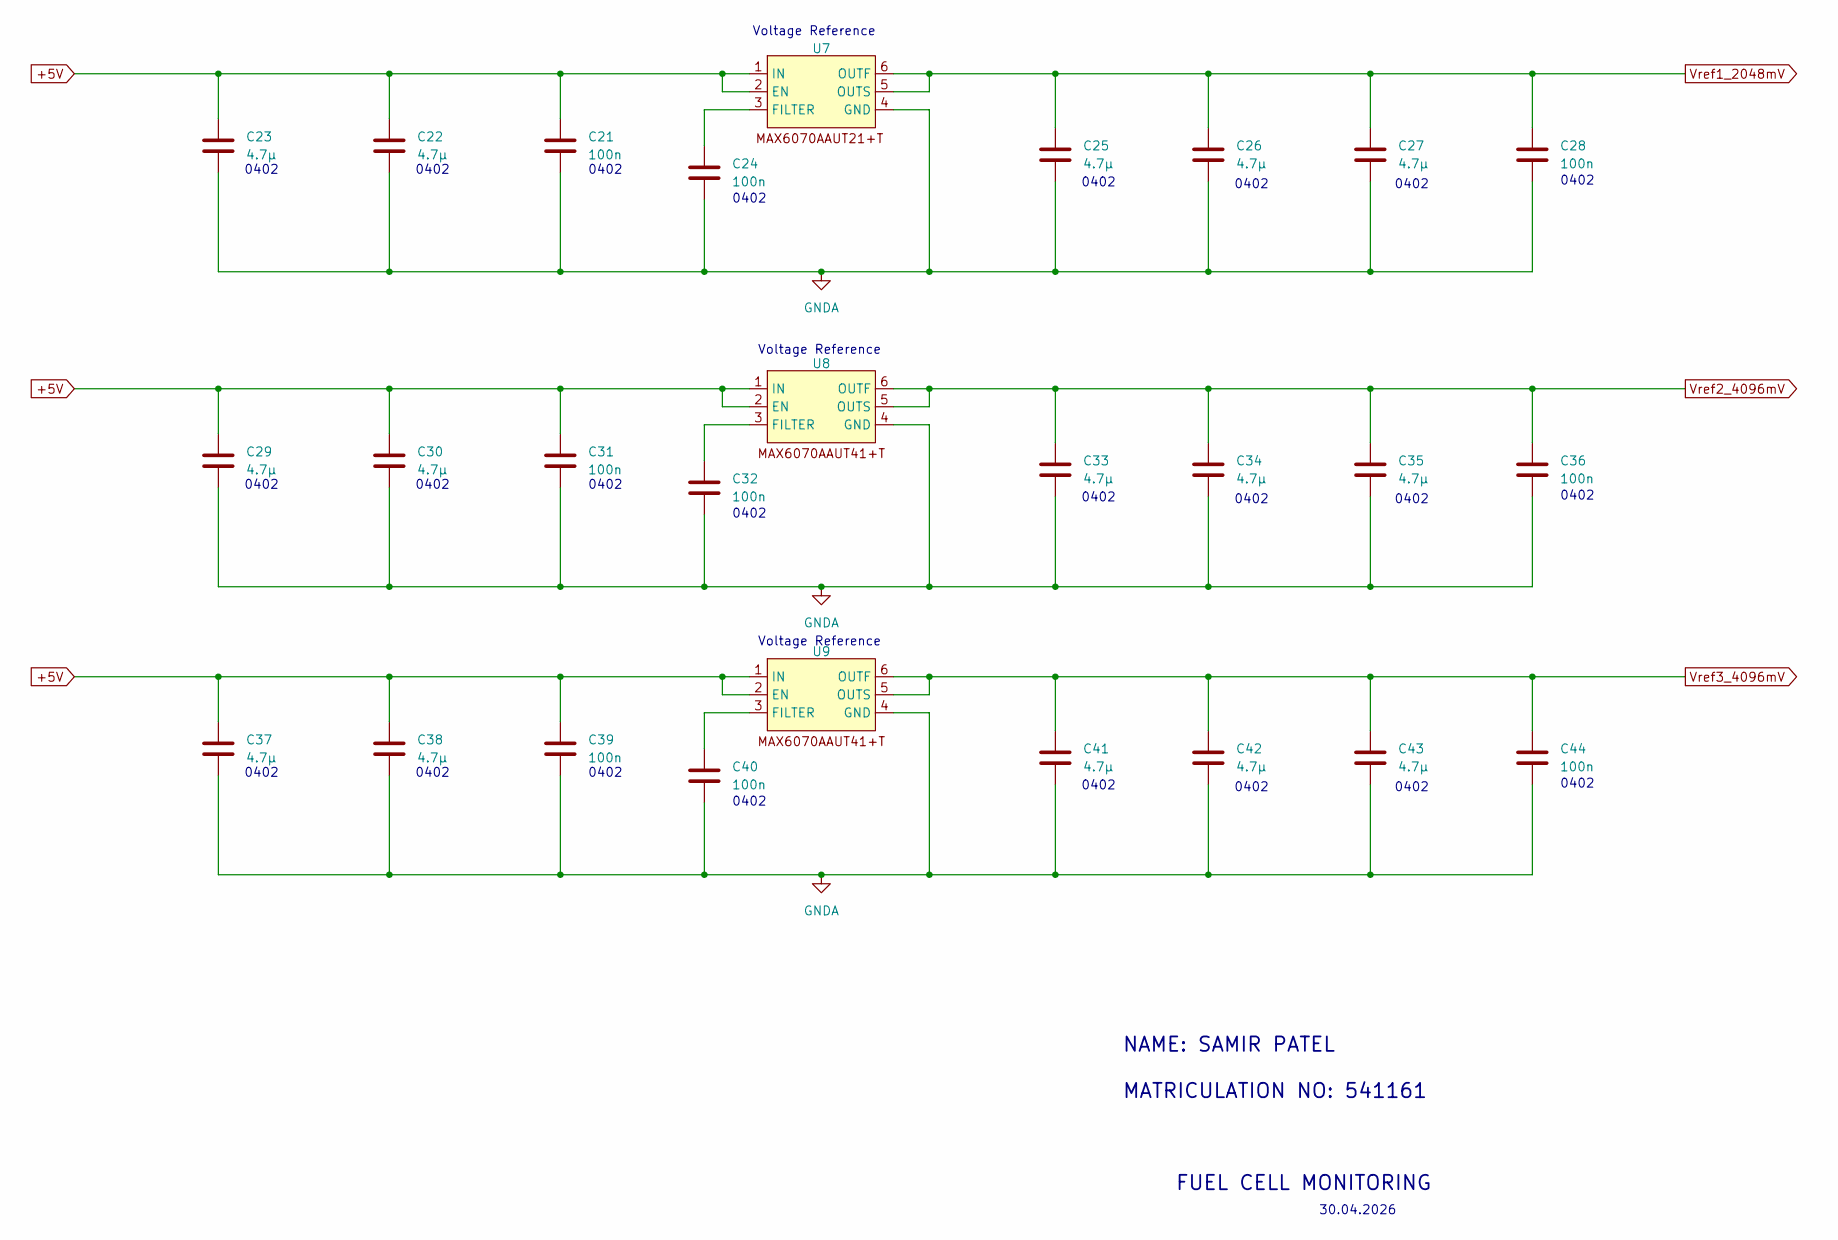
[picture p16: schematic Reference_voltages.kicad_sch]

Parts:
C21, C24, C28, C31, C32, C36, C39, C40, C44: 100n; C_0402_1005Metric
C22, C23, C25, C26, C27, C29, C30, C33, C34, C35, C37, C38, C41, C42, C43: 4.7µ; C_0402_1005Metric
U7: MAX6070AAUT21+T
U8, U9: MAX6070AAUT41+T

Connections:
+5V: C21.1, C22.1, C23.1, C29.1, C30.1, C31.1, C37.1, C38.1, C39.1, U7.1 (IN), U7.2 (EN), U8.1 (IN), U8.2 (EN), U9.1 (IN), U9.2 (EN); also elsewhere on the board
GNDA: C21.2, C22.2, C23.2, C24.2, C25.2, C26.2, C27.2, C28.2, C29.2, C30.2, C31.2, C32.2, C33.2, C34.2, C35.2, C36.2, C37.2, C38.2, C39.2, C40.2, C41.2, C42.2, C43.2, C44.2, U7.4 (GND), U8.4 (GND), U9.4 (GND); also elsewhere on the board
unnamed: C24.1, U7.3 (FILTER)
unnamed: C32.1, U8.3 (FILTER)
unnamed: C40.1, U9.3 (FILTER)
Vref1_2048mV: C25.1, C26.1, C27.1, C28.1, U7.5 (OUTS), U7.6 (OUTF); also elsewhere on the board
Vref2_4096mV: C33.1, C34.1, C35.1, C36.1, U8.5 (OUTS), U8.6 (OUTF); also elsewhere on the board
Vref3_4096mV: C41.1, C42.1, C43.1, C44.1, U9.5 (OUTS), U9.6 (OUTF); also elsewhere on the board

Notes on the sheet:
Voltage Reference
0402
30.04.2026
FUEL CELL MONITORING
NAME: SAMIR PATEL MATRICULATION NO: 541161

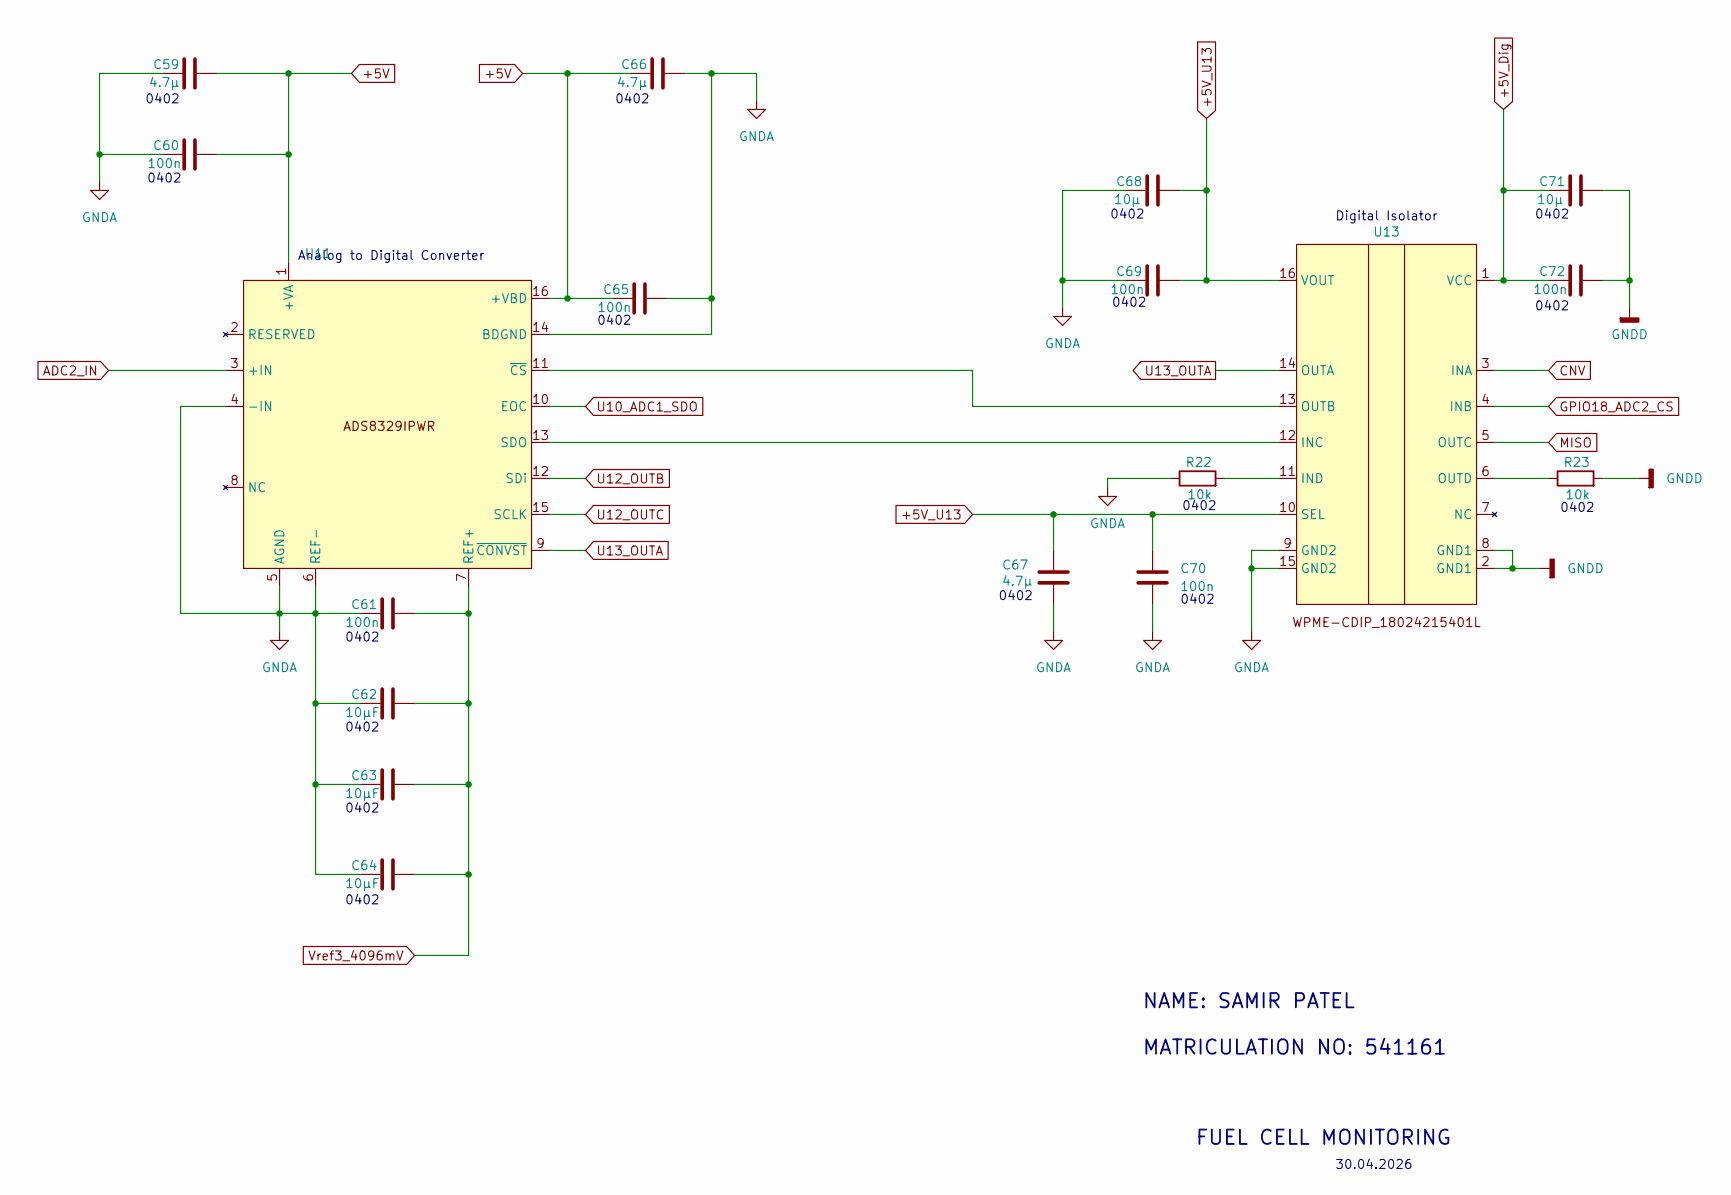
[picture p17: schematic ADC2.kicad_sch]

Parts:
C59, C66, C67: 4.7µ; C_0402_1005Metric
C60, C61, C65, C69, C70, C72: 100n; C_0402_1005Metric
C62, C63, C64: 10µF; C_0402_1005Metric
C68, C71: 10µ; C_0402_1005Metric
R22, R23: 10k; R_0402_1005Metric
U11: ADS8329IPWR
U13: WPME-CDIP 18024215401L

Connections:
+5V: C59.2, C60.2, C65.1, C66.1, U11.1 (+VA), U11.16 (+VBD); also elsewhere on the board
+5V_Dig: C71.1, C72.1, U13.1 (VCC); also elsewhere on the board
+5V_U13: C67.1, C68.2, C69.2, C70.1, U13.10 (SEL), U13.16 (VOUT)
ADC2_IN: U11.3 (+IN); also elsewhere on the board
CNV: U13.3 (INA); also elsewhere on the board
GNDA: C59.1, C60.1, C61.1, C62.1, C63.1, C64.1, C65.2, C66.2, C67.2, C68.1, C69.1, C70.2, R22.1, U11.4 (-IN), U11.5 (AGND), U11.6 (REF-), U11.14 (BDGND), U13.9 (GND2), U13.15 (GND2); also elsewhere on the board
GNDD: C71.2, C72.2, R23.2, U13.2 (GND1), U13.8 (GND1); also elsewhere on the board
GPIO18_ADC2_CS: U13.4 (INB); also elsewhere on the board
MISO: U13.5 (OUTC); also elsewhere on the board
unnamed: U11.13 (SDO), U13.12 (INC)
unnamed: U11.11 (~CS), U13.13 (OUTB)
unnamed: R22.2, U13.11 (IND)
unnamed: R23.1, U13.6 (OUTD)
U10_ADC1_SDO: U11.10 (EOC); also elsewhere on the board
U12_OUTB: U11.12 (SDi); also elsewhere on the board
U12_OUTC: U11.15 (SCLK); also elsewhere on the board
U13_OUTA: U11.9 (~CONVST), U13.14 (OUTA); also elsewhere on the board
Vref3_4096mV: C61.2, C62.2, C63.2, C64.2, U11.7 (REF+); also elsewhere on the board

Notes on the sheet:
Analog to Digital Converter
30.04.2026
Digital Isolator
0402
NAME: SAMIR PATEL MATRICULATION NO: 541161
FUEL CELL MONITORING

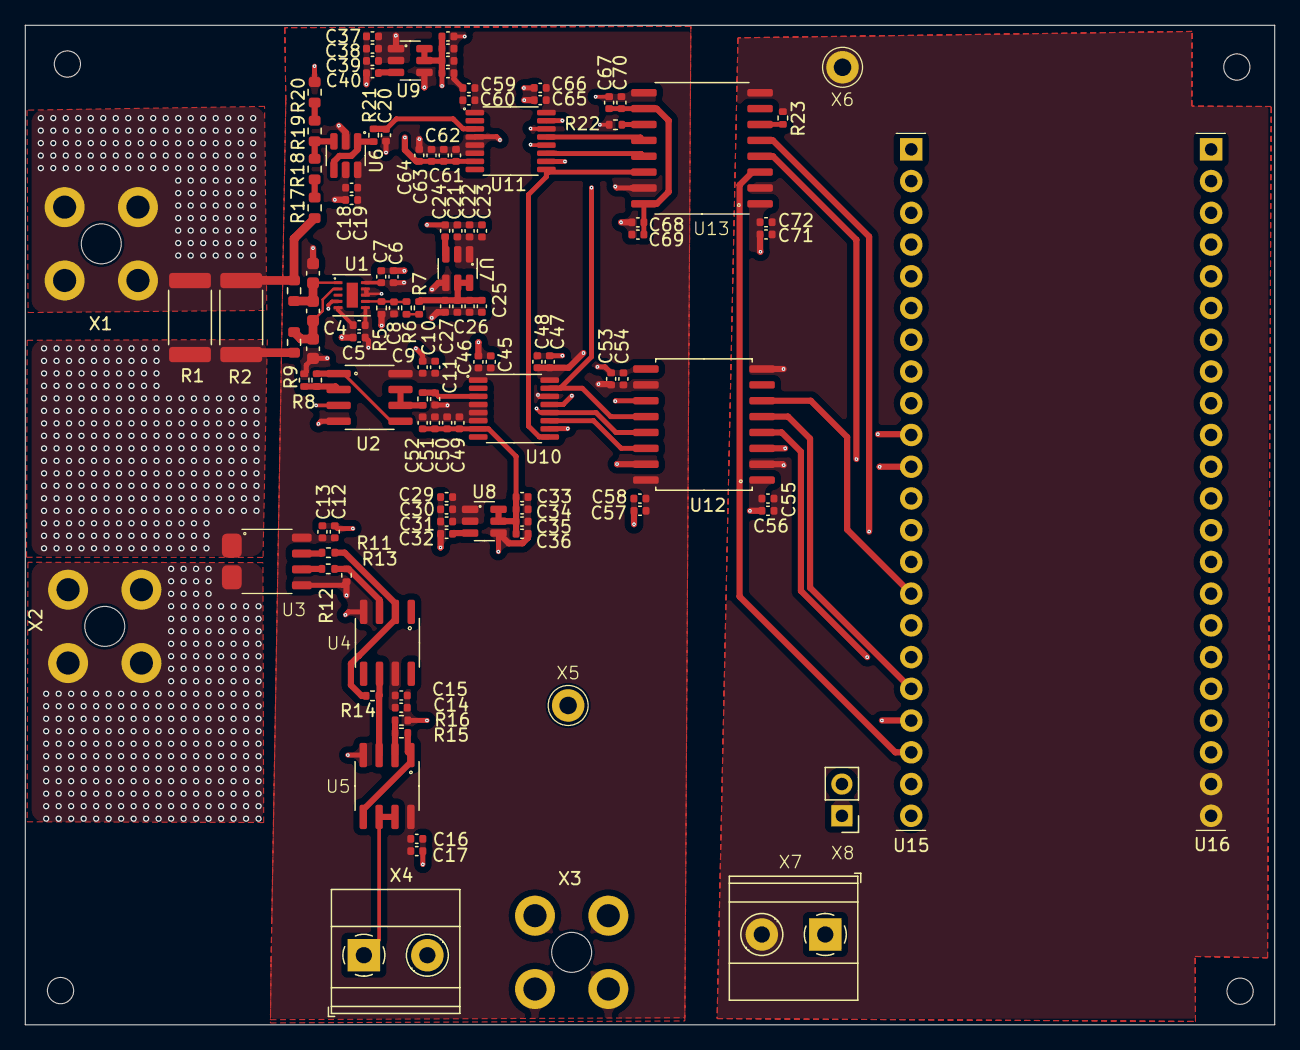
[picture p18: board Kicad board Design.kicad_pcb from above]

Board: 6 copper layers, 100.0 x 80.0 mm, 118 parts (0 on the bottom side), 54 nets.

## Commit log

2026-09-09 Initial release - fuel cell monitoring PCB
    [ADC1.kicad_sch, ADC2.kicad_sch, Current_Measurement.kicad_sch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]
2026-09-09 Revise fuel cell system description in README
    Updated README to remove specific power rating from fuel cell description.
2026-09-29 Remove KiCad temporary files
2026-09-29 Ignore KiCad cache files
